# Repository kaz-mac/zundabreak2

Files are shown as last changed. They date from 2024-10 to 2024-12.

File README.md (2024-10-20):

# 30分以上PCの前にいるとずんだもんが休憩を促すデバイス for M5Stack ATOMS3

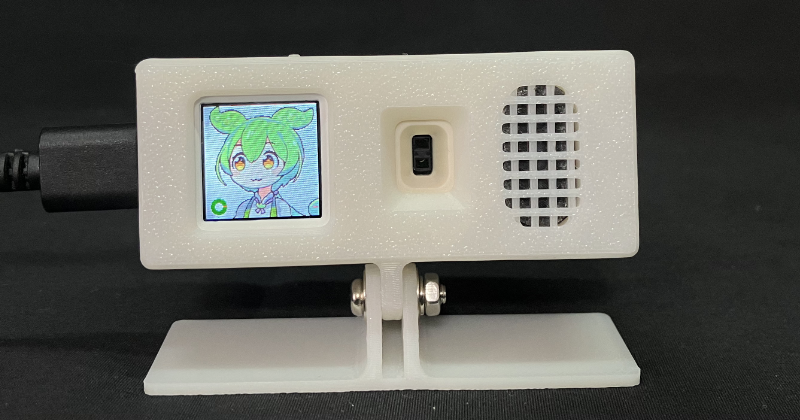
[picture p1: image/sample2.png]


## これは何？
30分以上PCの前にいたら休憩を促すメッセージを再生するデバイスです。PCの画面に長時間向かっていると目に負担がかかるので、目を休めつつ、気分転換を図るのが狙いです。腰痛防止にもいいのだ。

## 必要なもの
* M5Stack [ATOMS3](https://shop.m5stack.com/products/atoms3-dev-kit-w-0-85-inch-screen)
* M5Stack [Unit-ToF4M](https://shop.m5stack.com/products/time-of-flight-distance-unit-vl53l1x) (VL53L1X)
* M5Stack [Speaker 2 Hat](https://shop.m5stack.com/products/m5stickcplus-speaker-2-hat-max98357) (MAX98357)、（[ATOMIC Speaker Base](https://shop.m5stack.com/products/atomic-speaker-base-ns4168)も使用可）

## しくみ
ToFセンサーを使って対象物（人間）までの距離を測定します。指定した範囲内に人が存在する場合、PCの前にいると判断します。PCの前にいる時間が一定時間を超えると働きすぎと判断して、休憩を促すメッセージを再生します。

物体を検出するセンサーとしてはPIRセンサーが有名ですが、PIRセンサーでは距離が測れないため、PCの前にいるのか、離れた場所にいるのかを区別できません。また検知する角度も広いので他の人にも反応してしまいます。今回使用したUnit-ToF4Mは検知する範囲の角度が狭いので、人間くらいの大きさならピンポイントで測定できます。

## ディレクトリ構成
* [src/](src/) ... M5Stackのプログラム
* [psdlayers2rgb565/](psdlayers2rgb565/) ... PSD形式の画像からRGB565形式に一括変換するプログラム
* [STL/](STL/) ... ケースの3Dプリント用データ

<br>

# 作り方

## ライブラリのインストール
以下のライブラリがインストールされていない場合は、先にインストールします。
* M5Unified
* ESP8266Audio
* VL53L1X
* Ticker

## プログラムのコンパイル
zundabreak2 というフォルダを作成して、src/ フォルダ内のファイルをコピーします。コンパイルしてATOMS3に書き込みます。なお、オプション設定はUSB CDC On Boot: Enabled、USB Mode: Hardware CDC and JTAGにしています。

## ケースをプリントする場合
STLフォルダに3種類のケースが入っているので好きなのを使ってください。
* STL/Standard ... 改造・はんだ付け不要でジャンパーワイヤーで接続できます。
* STL/Mini ... コンパクトなタイプ。スピーカーをケースから取り出してはんだ付けします。
* STL/misc ... Miniのスタンド部分なしバージョン

脱落防止の突起があるのでケースを広げながら出し入れしてみてください。かなり硬めです。ATOMS3を取り出すときは、画面部分を強く押さないように注意！取り出すときはケースをニッパ等で破壊することを推薦します。

## ケースを使わない場合
[Speaker 2 Hat](https://shop.m5stack.com/products/m5stickcplus-speaker-2-hat-max98357) ではなく [ATOMIC Speaker Base](https://shop.m5stack.com/products/atomic-speaker-base-ns4168) を使えばジャンパーワイヤーなしで使えます。ピンアサインはATOMIC Speaker Baseに合わせていますので、そのままコンパイルしても使えます。

## 配線
はじめにATOMS3のGroveポートとToFセンサーを接続します。次にATOMS3のGPIOポートとスピーカーを接続します。ピンアサインは以下の通り。
| Speaker 2 HAT | ATOMS3 | 参考(M5StickC Plusのピンアサイン) |
| --- | --- | --- |
| GND | GND | GND |
|  |  | 5V |
| BCLK | G5 | G26 |
| SDATA | G38 | G36/G25 |
| LRCK | G39 | G0 |
|  |  | BAT |
| 3V3 | 3V3 | 3V3 |
|  |  | 5V |

Speaker 2 HATはM5StickC Plus用の製品なので、そのままでは使用できませんが、ATOMS3のGPIOに合わせて接続してあげれば使用できます。

## センサーが反応する距離を調整
自分の環境に合わせてセンサーが反応する距離を調整します。ボタン（画面の方）を押しながら電源を入れるとデバッグモードに入ります。デバッグモードでは距離(cm)と範囲のゲージが表示されるので、もし合わない場合は後述するカスタマイズのところを参考に値を修正してください。

## 電源オン
デフォルトでは指定した範囲内に居る場合は、アヒルちゃんが表示されます。ToFセンサーは指向性が高いので、正面に置いていると、体を動かしたときに範囲外になってしまうかもしれません。アヒルちゃんで確認しましょう。もし範囲外になって使いにくい場合は、横側に置くという手もあります。

## ボタン操作
短押し ... いきなり休憩モード<br>
長押し ... 次の状態へ遷移

<br>

# カスタマイズ

## 基本的なカスタマイズ方法
zundabreak2.ino の冒頭に設定項目があるので、好みで調整してください。
| 変数名 | 用途 | 単位 | デフォルト値 |
| --- | --- | --- | --- |
| WORK_LIMIT | 休憩を促すまでの時間 | s | 1800 | 
| BREAK_TIME_LONG | 休憩の長さ | s | 90 |
| DISPLAY_DISTANCE_MIN | PCの前にいると判断する位置 MIN | mm | 250 |
| DISPLAY_DISTANCE_MAX | PCの前にいると判断する位置 MAX | mm | 750 |
```cpp
const uint32_t WORK_LIMIT = 1800;       // 30分以上働いたら休憩を促す(s)
const uint32_t BREAK_TIME_LONG = 90;    // 休憩の長さ(s)
const int DISPLAY_DISTANCE_MIN = 250;   // PCの前にいると判断する位置 MIN (mm)
const int DISPLAY_DISTANCE_MAX = 750;   // PCの前にいると判断する位置 MAX (mm)
```

## 応用的ななカスタマイズ
```cpp
const int TIRED_LIMIT_1 = 85;   // 疲労レベル閾値1 (0-100)  85=約25分後
const int TIRED_LIMIT_2 = 95;   // 疲労レベル閾値2 (0-100)  95=約28分後
const bool SHOW_DISTANCE_GAUGE = true;  // 距離確認用のゲージを常に表示する
const bool SHOW_DISTANCE_AHIRU = true;  // 距離確認用のアヒルちゃんを表示する
const uint32_t BLINK_TIME_BASE = 2000;  // まばたき時間　基本間隔
const uint32_t BLINK_TIME_RAND = 2000;  // まばたき時間　ランダム追加 max
const uint32_t BLINK_TIME_CLOS = 150;   // まばたき時間　閉じてる時間
const uint32_t KYORO_TIME_BASE = 1500;  // キョロキョロ時間　基本間隔
const uint32_t KYORO_TIME_RMAX = 2000;  // キョロキョロ時間　ランダム追加 max
```

## 音声を変えたい
自分でWAVファイルを作成することもできます。data_sound_zundamon.h に変数名のところを変えてデータをコピペしてください。変換は psdlayers2rgb565/ に入ってる file2h.py を使うと便利です。Pythonが必要です。ビットレートを24KHz以外にする場合は適宜修正してください。
```
python file2h.py input.wav output.h
```

## 音量を変えたい
WAVファイル作成の段階で変更する必要があるそうです。（とChatGPTが言ってた）

## 表情を変えたい
ずんだもんのアバターは体、右腕、左腕、眉毛、目、口、アヒルちゃん、それぞれのパーツを組み合わせて生成されています。この数字の部分を変えれば別のパーツになります。番号は data_image_zundamon128.h の「画像パーツの部位別テーブル」のところを参考にしてみてください。
```cpp
  avatar.changeParts("body", 0);    // 体
  avatar.changeParts("rhand", 0);   // 右腕
  avatar.changeParts("lhand", 0);   // 左腕
  avatar.changeParts("eyebrow", 0); // 眉毛
  avatar.changeParts("eye", 1);     // 目
  avatar.changeParts("mouth", 0);   // 口
  avatar.changeParts("ahiru", 0);   // アヒル
```
なお、まばたきやキョロキョロ（視線を左右に変えること）は別途設定しています。キョロキョロは変数 kyoroEyePattern で設定しています。
```cpp
const uint8_t kyoroEyePattern[3][kyoroEyeNum] = {  // キョロキョロする目のインデックス番号：目　普通
  { 3,1,2,1 }, { 6,4,5,4 }, { 9,7,8,7 }   // 元気なとき、少し疲れたとき、かなり疲れたとき
};
```
まばたきは以下のように設定しています。
```cpp
avatar.setBlink("eye", 1, 0);
```

## 別の画像を使いたい
ずんだもんじゃなくて四国めたんがいいですか？ psdlayers2rgb565/ はPSD形式の画像ファイルからC++のソースコード形式に変換するプログラムが入ってますので、これを使えばできると思います。Pythonが必要です。詳しくは[こちら](https://github.com/kaz-mac/zundachan/tree/main/tools)にあるズンダチャン用に作ったドキュメントを参考にしてください。

主な同梱ファイル
* image_zundamon128.ini ... 坂本アヒルさんのずんだもん立ち絵素材から.hファイルに変換するための設定ファイル
* convert_zundamon128.bat ... 一連の変換処理を一発で行うバッチファイル
設定ファイルの記述方法は image_zundamon128.ini にコメントがあります。

## License
個別に表記しているものを除き、プログラムは[MIT license](https://opensource.org/licenses/MIT)です。<br>
音声データ、画像データ、およびキャラクターに関してはライセンス・利用規約が異なります。

[東北ずん子ずんだもんプロジェクト　キャラクター　利用の手引き](https://zunko.jp/guideline.html)<br>
[ずんだもん立ち絵素材](https://www.pixiv.net/artworks/92641351)<br>
[VOICEVOX ソフトウェア利用規約](https://voicevox.hiroshiba.jp/term/)<br>

## Credit
* 画像データ 坂本アヒルさん
* キャラクター 東北ずん子ずんだもんプロジェクト
* 音声データ VOICEVOX: ずんだもん

## 作例
STL/Standatd/ のケースを使用した場合（ジャンパーワイヤーで配線）
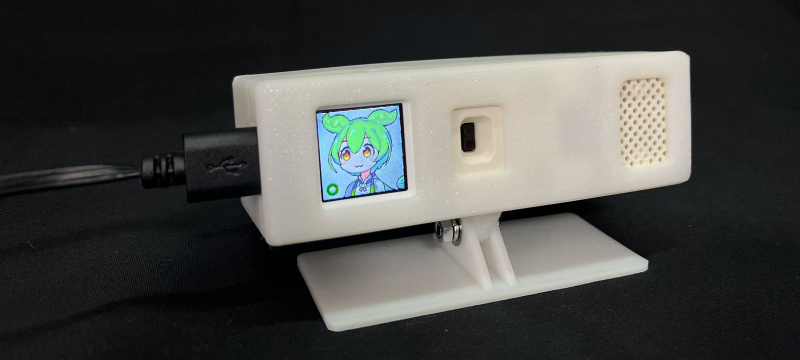
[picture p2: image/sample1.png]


STL/Mini/ のケースを使用した場合（内部）
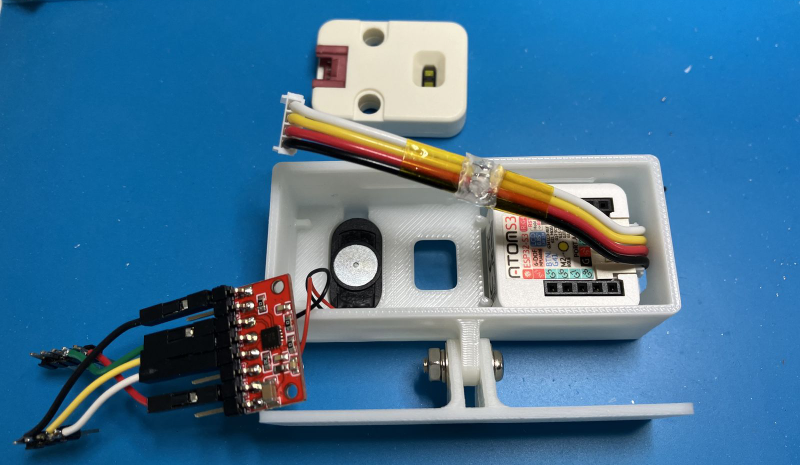
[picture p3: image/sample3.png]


ATOMIC Speaker Baseを使用した例
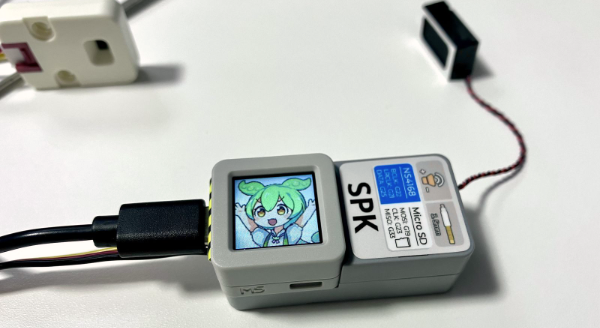
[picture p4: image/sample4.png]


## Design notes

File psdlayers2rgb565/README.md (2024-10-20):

# 概要
PSD形式の画像ファイルからレイヤーを抽出して合成し、Arduino用で使用できるC++のソースコード形式(RGB565)に変換するツールです。サウンドファイル等のバイナリデータをソースコード形式に変換するツールも含まれています。

# ドキュメント
このプログラムはズンダチャンに収録したツールの一部です。詳しくはこちらのドキュメントを参考にしてください。<br>
[https://github.com/kaz-mac/zundachan/tree/main/tools](https://github.com/kaz-mac/zundachan/tree/main/tools)

# 本プロジェクト用に作成したファイル
* image_zundamon128.ini - ずんだもん 分解設定ファイル 128x128用
* convert_zundamon128.bat - 一連の変換処理を一括で行うバッチファイル

# ライブラリのインストール
```
pip install pillow
pip install psd-tools
```
Python 3.11で動作確認。3.13ではpsd-toolsがインストールできなかった。

# 使用例
PSD画像を分解
```
python psdlayers2png.py "ずんだもん立ち絵素材2.3.psd" image_zundamon128_png
```
分解した画像データを.hファイルに変換
```
python pngmerger_rgb565.py image_zundamon128.ini image_zundamon128_png zundamon128.h
```
WAVファイルを.hファイルに変換
```
python file2h.py input.wav output.h
```

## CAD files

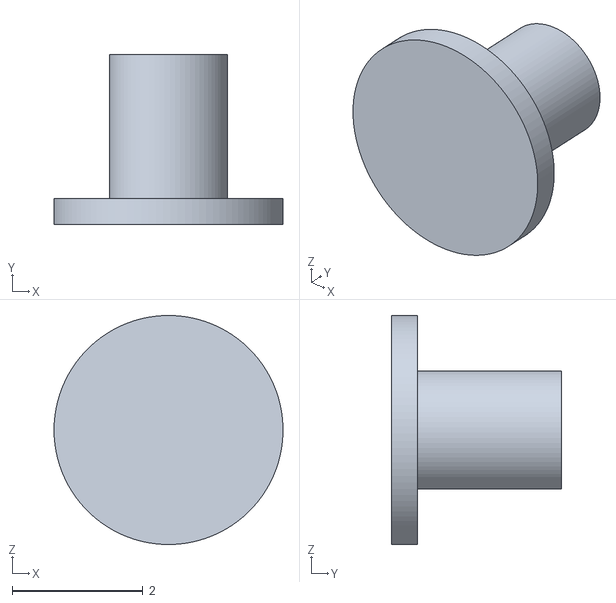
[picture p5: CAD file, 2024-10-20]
STL/Mini/Zuntimer_Mbutton.stl
3.50 x 2.60 x 3.50

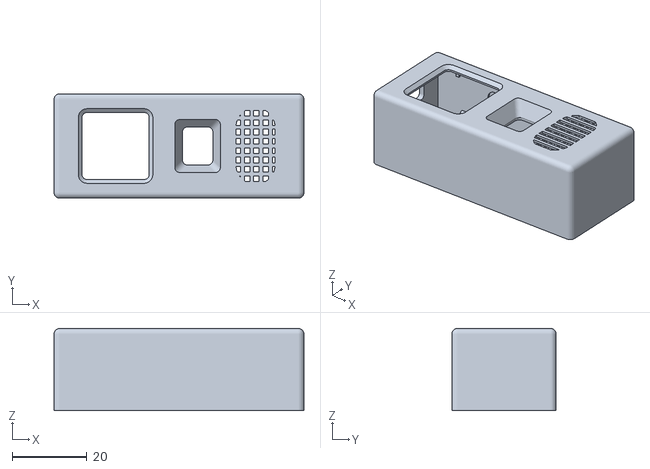
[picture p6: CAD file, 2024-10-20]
STL/misc/Zuntimer_Mbody_without_stand.stl
67.0 x 28.0 x 22.0

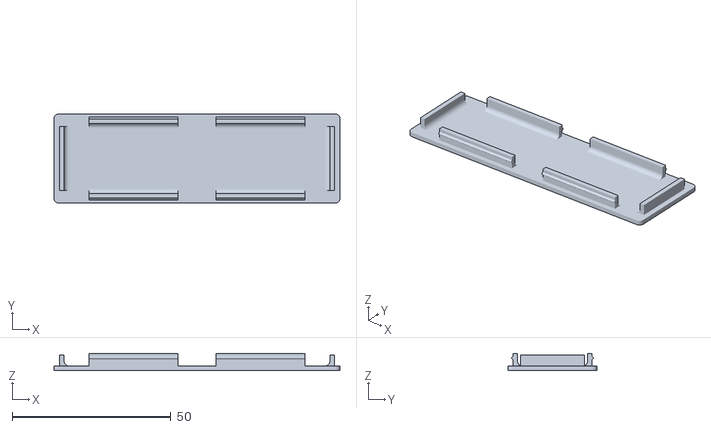
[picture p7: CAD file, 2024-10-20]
STL/Standard/Zuntimer_cover.stl
90.0 x 28.0 x 5.50

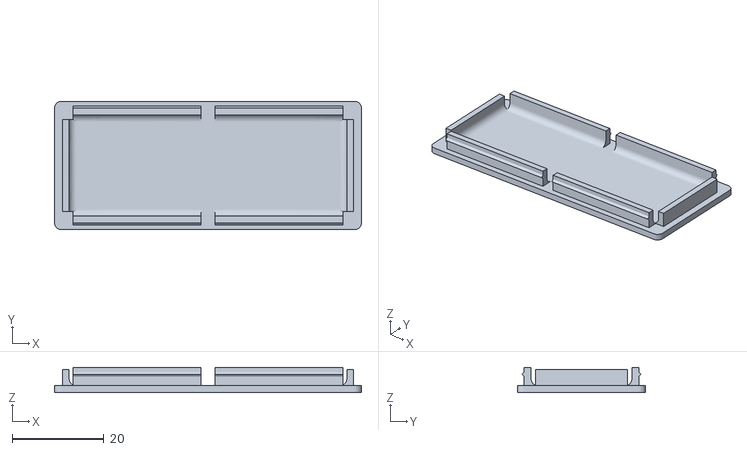
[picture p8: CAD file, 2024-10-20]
STL/Mini/Zuntimer_Mcover.stl
67.0 x 28.0 x 5.50

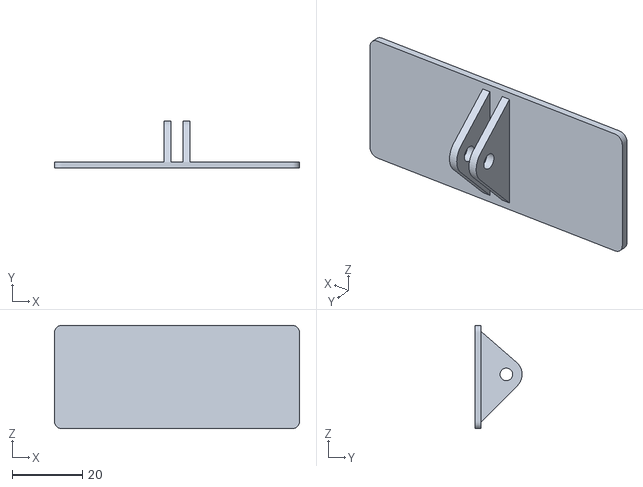
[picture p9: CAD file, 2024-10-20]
STL/Standard/Zuntimer_stand.stl
70.0 x 13.5 x 29.5

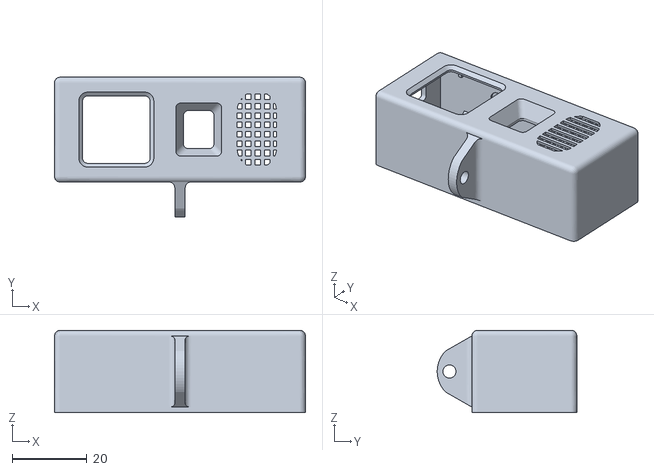
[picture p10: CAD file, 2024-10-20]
STL/Mini/Zuntimer_Mbody.stl
67.0 x 37.3 x 22.0

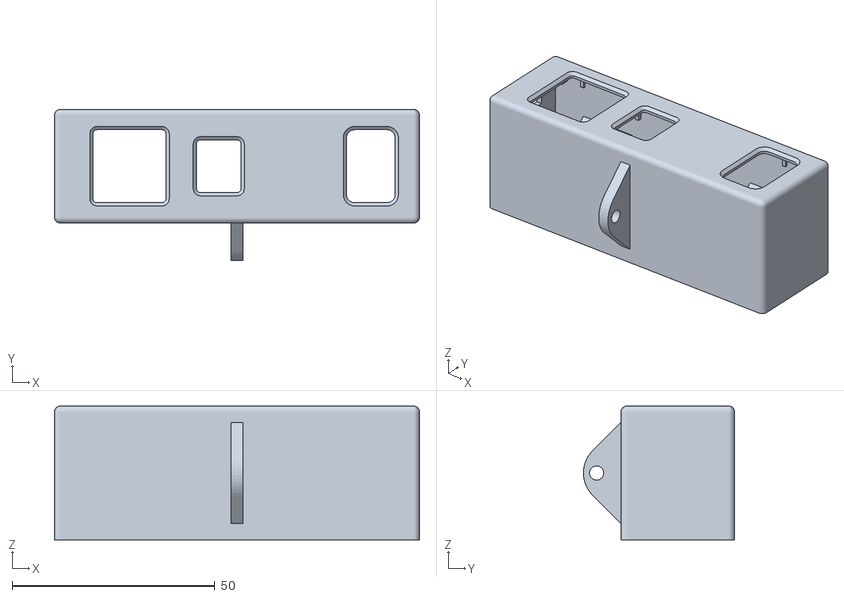
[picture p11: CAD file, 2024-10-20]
STL/Standard/Zuntimer_body.stl
90.0 x 37.3 x 33.0

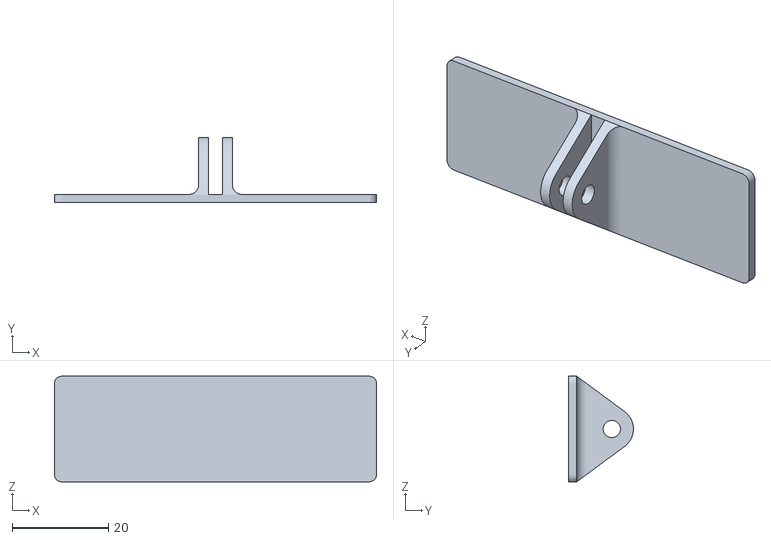
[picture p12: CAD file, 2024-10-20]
STL/Mini/Zuntimer_Mstand.stl
67.0 x 13.5 x 22.0

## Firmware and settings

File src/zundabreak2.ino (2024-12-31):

/*
  zundabreak2.ino
  30分以上PCに向かっているとずんだもんが休憩を促すデバイス for M5Stack ATOMS3
  ToFセンサー Unit-ToF4M使用

  Copyright (c) 2024 Kaz  (https://akibabara.com/blog/)
  Released under the MIT license.
  see https://opensource.org/licenses/MIT

  CREDIT
    画像データ 坂本アヒルさん
    キャラクター　東北ずん子ずんだもんプロジェクト
    音声データ VOICEVOX: ずんだもん

  ※本プログラムはMITライセンスですが（個別に記載があるものを除く）、
  音声データ、画像データ、およびキャラクターに関しては、それぞれの
  ライセンス・利用規約が適用されます。
*/
/*
TODO:
  Ticker once_msでも良くない？
  deep sleepに対応したい　参考 https://qiita.com/yomori/items/ef20d888a79aaedb58fe
*/
#include <M5Unified.h>

// 基本動作設定
const uint32_t WORK_LIMIT = 1800;       // 30分以上働いたら休憩を促す(s)
const uint32_t BREAK_TIME_LONG = 90;    // 休憩の長さ(s)
const int DISPLAY_DISTANCE_MIN = 250;   // PCの前にいると判断する位置 MIN (mm)
const int DISPLAY_DISTANCE_MAX = 750;   // PCの前にいると判断する位置 MAX (mm)

// その他動作設定
const int TIRED_LIMIT_1 = 85;   // 疲労レベル閾値1 (0-100)  85=約25分後
const int TIRED_LIMIT_2 = 95;   // 疲労レベル閾値2 (0-100)  95=約28分後
const bool SHOW_DISTANCE_GAUGE = true;  // 距離確認用のゲージを常に表示する
const bool SHOW_DISTANCE_AHIRU = true;  // 距離確認用のアヒルちゃんを表示する
const uint32_t BLINK_TIME_BASE = 2000;  // まばたき時間　基本間隔
const uint32_t BLINK_TIME_RAND = 2000;  // まばたき時間　ランダム追加 max
const uint32_t BLINK_TIME_CLOS = 150;   // まばたき時間　閉じてる時間
const uint32_t KYORO_TIME_BASE = 1500;  // キョロキョロ時間　基本間隔
const uint32_t KYORO_TIME_RMAX = 2000;  // キョロキョロ時間　ランダム追加 max

// GPIO設定 ATOMS3
#define GPIO_SDA  2   // Grove SDA
#define GPIO_SCL  1   // Grove SCL
#define GPIO_I2S_BCLK  5    // I2S BCLK (Atomic SPK Base compatible)
#define GPIO_I2S_LRCK  39   // I2S LRCK (Atomic SPK Base compatible)
#define GPIO_I2S_DATA  38   // I2S DATA (Atomic SPK Base compatible)

// アバター関連
#include "Zundavatar.h"   // アバタークラス
using namespace zundavatar;
bool lcdBusy = false;   // ディスプレイの排他制御用　クラス間で共有される
Zundavatar avatar(&lcdBusy);

// アバター画像データ
#include "data_image_zundamon128.h"   // 画像データ　ずんだもん

// オーディオ出力関連
#include <AudioFileSourcePROGMEM.h>
#include <AudioGeneratorWAV.h>
#include <AudioOutputI2S.h>
AudioGeneratorWAV *wav;
AudioFileSourcePROGMEM *file;
AudioOutputI2S *out;

// 音声データ
#include "data_sound_zundamon.h"   // 音声データ　ずんだもん
const int SAMPLE_RATE = 24000;
const unsigned char* soundData[] = { sound000, sound001, sound002 };
const size_t sizeData[] = { sizeof(sound000), sizeof(sound001), sizeof(sound002) };

// ToF距離センサー関係 Unit-ToF4M使用
#include <Wire.h>
#include <VL53L1X.h>
VL53L1X tof;

// 割り込み処理
#include <Ticker.h>
Ticker tickerk;
volatile bool refresh;

// グローバル変数
M5Canvas tgauge, tinfo;
M5Canvas red, blue, green, purple;
bool blink = false;
uint16_t blinkOpen = 1;
bool kyoro = false;
bool tofok = false;

// デバッグに便利なマクロ定義 -- M5.Log置き換えver --------
// 参考ページ https://github.com/lovyan03/M5Unified_HandsOn/blob/main/sample_code/Log1.cpp
#define sp(x) M5.Log.println(String(x).c_str())
#define spn(x) M5.Log.print(String(x).c_str())
#define spp(k,v) M5.Log.println(String(String(k)+"="+String(v)).c_str())
#define spf(fmt, ...) M5.Log.printf(fmt, __VA_ARGS__)
#define array_length(x) (sizeof(x) / sizeof(x[0]))


// ====================================================================================

// 体力ゲージのイメージを作成する
void drawHpGage(M5Canvas* canvas, int tired) {
  int c;
  int w = canvas->width();
  int h = canvas->height();
  canvas->fillSprite(0x0020);   // 透明色で塗りつぶし
  c = 360 * ((float)(100 - tired) / 100.0);
  canvas->fillArc(w/2,h/2, 5,9, 0,c, TFT_DARKGREEN);
  if (c > 0) canvas->fillArc(w/2,h/2, 5,9, c,360, TFT_RED);
}

// 距離ゲージのイメージを作成する
void drawDistanceGage(M5Canvas* canvas, int now, int limitLow, int limitHigh, int maxDepth=4000) {
  int y;
  int w = canvas->width();
  int h = canvas->height();
  if (now < 0) now = 0;
  if (now > maxDepth) now = maxDepth;
  //canvas->fillSprite(TFT_WHITE);   // 背景色で塗りつぶし
  canvas->fillSprite(0x0020);   // 透明色で塗りつぶし
  y = (h-1) - (h-1) * ((float)limitLow / maxDepth);
  canvas->drawLine(w/2,y, w-1,y, TFT_DARKGREEN);
  y = (h-1) - (h-1) * ((float)limitHigh / maxDepth);
  canvas->drawLine(w/2,y, w-1,y, TFT_DARKGREEN);
  y = (h-1) - (h-1) * ((float)now / maxDepth);
  canvas->drawLine(0,y, w-1,y, TFT_RED);
}

// デバッグモード：矢印付きゲージのイメージを作成する
void drawArrowGage(M5Canvas* canvas, int now, int limitLow, int limitHigh, int maxDepth=4000) {
  int x, y, x1, x2;
  int w = canvas->width();
  int h = canvas->height();
  if (now < 0) now = 0;
  if (now > maxDepth) now = maxDepth;
  canvas->fillSprite(0x0020);   // 透明色で塗りつぶし
  canvas->drawRect(1,9, w-2, 12, TFT_BLACK);
  canvas->fillRect(2,10, w-4, 10, TFT_SKYBLUE);
  x1 = (w-4) * ((float)limitLow / maxDepth);
  x2 = (w-4) * ((float)limitHigh / maxDepth);
  canvas->fillRect(x1+2,10, (x2-x1), 10, TFT_GREEN);
  x = (w-4) * ((float)now / maxDepth);
  y = 8;
  canvas->fillRect(x-1,1, 3,h-1, TFT_RED);
  canvas->fillTriangle(x,y, x-6,y-7, x+6, y-7, TFT_RED);
}

// デバッグモード：距離メーターのイメー時を作成する
void drawDebugDistance(M5Canvas* canvas, int distance, bool fuchi=false) {
  int w = canvas->width();
  int x, y;
  canvas->fillSprite(0x0020);   // 透明色で塗りつぶし
  canvas->setFont(&fonts::Font4); // 14x26
  canvas->setTextDatum(textdatum_t::top_right);
  String text = String(distance / 10) + "cm";
  x = w - 2;
  y = 2;
  if (fuchi) {
    canvas->setTextColor(TFT_WHITE);
    for (int i=-1; i<=1; i++) {
      for (int j=-1; j<=1; j++) {
        canvas->drawString(text, x+i, y+j);
      }
    }
  }
  canvas->setTextColor(TFT_BLACK);
  canvas->drawString(text, x, y);
}

// デバッグモード：ToFセンサー距離調整をするためのモード
void debugmode() {
  // ゲージと距離表示のcanvasを作成
  tgauge.setColorDepth(16);
  tgauge.createSprite(128, 20);
  avatar.setInsertedLayer(0, OVR_FRONT_AVATER, &tgauge, 0,108);   // ゲージのcanvasをアバターに挿入設定
  tinfo.setColorDepth(16);
  tinfo.createSprite(80, 30);
  avatar.setInsertedLayer(1, OVR_FRONT_AVATER, &tinfo, 128-80,0);   // 距離メーターのcanvasをアバターに挿入設定
  while (1) {
    M5.update();
    // 距離を測定
    int distance = tof.readRangeContinuousMillimeters();
    spp("distance",distance);
    // 距離に応じてずんだもんの表情を変える
    defaultAvatarParts();
    if (distance < DISPLAY_DISTANCE_MIN) {  // 近すぎる場合
      avatar.changeParts("eye", 13);     // 目　ジト目
      avatar.changeParts("mouth", 11);   // 口　△
      avatar.changeParts("rhand", 3);   // 右腕　口元
    } else if (distance > DISPLAY_DISTANCE_MAX) { // 遠すぎる場合
      avatar.changeParts("body", 1);    // 体　萎え
      avatar.changeParts("eye", 14);     // 目　なごみ
    } else {  // 範囲内の場合
      avatar.changeParts("eye", 1);     // 目　普通　開く（中）
      avatar.changeParts("mouth", 1);   // 口　普通　（ほあー）
      avatar.changeParts("rhand", 2);   // 右腕　上げ
      avatar.changeParts("lhand", 2);   // 左腕　上げ
    }
    drawArrowGage(&tgauge, distance, DISPLAY_DISTANCE_MIN, DISPLAY_DISTANCE_MAX, 1500); // ゲージを作成
    drawDebugDistance(&tinfo, distance, true);  // 距離メーターを作成
    avatar.drawAvatar(); // アバター全体表示
    delay(100);
  }
}

// 配列の中に指定した値があるか？
// bool inArray(uint16_t value, const uint16_t* array, size_t size) {
//   for (size_t i = 0; i < size; i++) {
//     if (array[i] == value) return true;
//   }
//   return false;
// }

// アバターのパーツをデフォルトに設定する
void defaultAvatarParts() {
  avatar.changeParts("body", 0);    // 体
  avatar.changeParts("rhand", 0);   // 右腕
  avatar.changeParts("lhand", 0);   // 左腕
  avatar.changeParts("eyebrow", 0); // 眉毛
  avatar.changeParts("eye", 1);     // 目
  avatar.changeParts("mouth", 0);   // 口
  avatar.changeParts("ahiru", 0);   // アヒル
}

// 指定時間待機する。待機中もM5.update()を行っており、ボタンが押されたら即座に抜ける
bool waitMillis(uint32_t ms) {
  bool res = false;
  uint32_t tmwait = millis() + ms;
  while (millis() < tmwait) {
    M5.update();
    if (M5.BtnA.isPressed()) {
      res = true;
      break;
    }
    delay(10);
  }
  return res;
}

// 喋ると同時にリップシンクを行う
void playVoice(int no, bool withlip) {  // Default: withlip=false
  const int lipsyncDuration = 200;  // リップシンクの間隔(ms)
  unsigned long stams = millis();
  unsigned long lastms = 0;

  // 再生開始
  file = new AudioFileSourcePROGMEM(soundData[no], sizeData[no]);
  wav = new AudioGeneratorWAV();
  wav->begin(file, out);
  while (wav->isRunning()) {
    wav->loop();

    // リップシンク
    if (withlip && (millis() - lastms) >= lipsyncDuration) {
      // 平均音量を計算
      int idx = ((millis() - stams) * SAMPLE_RATE) / 1000 * 2;
      int numSamples = (lipsyncDuration * SAMPLE_RATE) / 1000;
      int totalSamples = 0;
      long totalVolume = 0;
      for (int i = 0; i < numSamples; i++) {
        if ((idx + i*2 + 1) >= sizeData[no]) break;
        int16_t val = soundData[no][idx + i*2] | (soundData[no][idx + i*2 + 1] << 8);
        totalVolume += abs(val);
        totalSamples++;
      }
      int averageVolume = (totalSamples > 0) ? totalVolume / totalSamples : 0;
      // 音の大きさに合わせてアバターの口を変更（閾値は要調整）
      if (averageVolume > 1000)     avatar.setLipsyncVowel(5, 80);  // "o" 80ms  口　お　（お）
      else if (averageVolume > 100) avatar.setLipsyncVowel(2, 80);  // "a" 80ms　口　あ　（ほあー）
      else                          avatar.setLipsyncVowel(0, 1);   // "n" 1ms
      lastms = millis();
    }
    delay(5);
  }

  // 再生終了
  wav->stop();
  if (withlip) avatar.setLipsyncVowel(0, 1);
}

// Tiker処理：自動的にキョロキョロする（描画はせず、refreshフラグを立てるのみ）
uint16_t kyoroEyeSelect = 0;  // キョロキョロパターンの選択
static constexpr uint16_t kyoroEyeNum = 4;      // キョロキョロする目の数
const uint8_t kyoroEyePattern[3][kyoroEyeNum] = {  // キョロキョロする目のインデックス番号：目　普通
  { 3,1,2,1 }, { 6,4,5,4 }, { 9,7,8,7 }   // 元気なとき、少し疲れたとき、かなり疲れたとき
};
void startKyorokyoro() {
  if (tickerk.active()) return;
  uint32_t kyoroms = KYORO_TIME_BASE + random(0, KYORO_TIME_RMAX);
  tickerk.attach_ms(kyoroms, tickerKyorokyoro);
}
void tickerKyorokyoro() {
  static uint16_t pat = 0;
  int krrand = random(0,3);// pat++ % kyoroEyeNum
  if (blink) {
    avatar.setBlink("eye", kyoroEyePattern[kyoroEyeSelect][krrand], 0);   // まばたきの目の設定を変更　注意：変更すると即座に反映されるのでrefreshは不要
  } else {
    avatar.changeParts("eye", kyoroEyePattern[kyoroEyeSelect][krrand]);   // 目を変更
    refresh = true;
  }
  // 次回実行間隔をランダムに変える
  if (tickerk.active()) {
    uint32_t kyoroms = KYORO_TIME_BASE + random(0, KYORO_TIME_RMAX);
    tickerk.detach();
    tickerk.attach_ms(kyoroms, tickerKyorokyoro);
  }
}
void stopKyorokyoro() {
  if (!tickerk.active()) return;
  tickerk.detach();
}

// 空きメモリ確認
void debug_free_memory(String str) {
  sp("## "+str);
  spf("heap_caps_get_free_size(MALLOC_CAP_DMA):%d\n", heap_caps_get_free_size(MALLOC_CAP_DMA) );
  spf("heap_caps_get_largest_free_block(MALLOC_CAP_DMA):%d\n", heap_caps_get_largest_free_block(MALLOC_CAP_DMA) );
  spf("heap_caps_get_free_size(MALLOC_CAP_SPIRAM):%d\n", heap_caps_get_free_size(MALLOC_CAP_SPIRAM) );
  spf("heap_caps_get_largest_free_block(MALLOC_CAP_SPIRAM):%d\n\n", heap_caps_get_largest_free_block(MALLOC_CAP_SPIRAM) );
}

// ====================================================================================

// 初期化
void setup() {
  // 初期化
  auto cfg = M5.config();
  // cfg.external_spk = true;  // 別に設定しなくても変わらなかったから意味ないかも??
  // cfg.serial_baudrate = 115200;
  M5.begin(cfg); 
  Wire.begin(GPIO_SDA, GPIO_SCL);
  delay(1000);
  sp("Start!");
  debug_free_memory("Start");

  // ログレベルの設定
  // M5.Log.setLogLevel(m5::log_target_serial, ESP_LOG_INFO); // 表示するログレベル ERROR WARN INFO DEBUG VERBOSE
  // M5.Log.setEnableColor(m5::log_target_serial, false);  // ログカラー

  // スピーカーI2S出力設定
  out = new AudioOutputI2S();
  out->SetPinout(GPIO_I2S_BCLK, GPIO_I2S_LRCK, GPIO_I2S_DATA);       // BCLK, DATA, LRCLK
  out->SetRate(SAMPLE_RATE);

  // ディスプレイの設定
  M5.Lcd.init();
  M5.Lcd.setRotation(3);
  M5.Lcd.setColorDepth(16);
  M5.Lcd.fillScreen(TFT_WHITE);

  // ToFセンサーの設定
  tof.setBus(&Wire);
  tof.setTimeout(500);
  tofok = tof.init();
  if (tofok) {
    tof.setDistanceMode(VL53L1X::Long);
    tof.setMeasurementTimingBudget(50000);
    tof.startContinuous(50);
  } else {
    sp("Failed to detect and initialize ToF sensor!");
    M5.Lcd.fillScreen(TFT_RED);
    delay(3000);
  }

  // アバターの設定
  avatar.usePSRAM(false);   // PSRAMを使わない（128x128ならメインメモリに収まるし速度も速いから）
  String tableNames[]   = { "body", "rhand", "lhand", "eyebrow", "eye", "mouth", "ahiru" };  // 部位名（imgTablesと順番を揃える）
  uint16_t* imgTables[] = { imgTableBody, imgTableRhand, imgTableLhand, imgTableEyebrow, imgTableEye, imgTableMouth, imgTableAhiru };  // 部位ごとにリスト化した表（テーブル）
  avatar.setImageData(imgInfo, tableNames, imgTables, 7); // 画像データを登録する
  avatar.useAntiAliases = true; // アンチエイリアス処理をする
  avatar.mirrorImage = false;   // 左右反転しない（反転はバグあり）
  avatar.setDrawDisplay(&M5.Lcd, 0,0, TFT_WHITE); // アバターの表示先を設定する（出力先, x, y, 背景色）
  avatar.debugtable();
  debug_free_memory("after avater setting");

  // アバターの表示
  defaultAvatarParts(); // アバターのパーツをデフォルトに設定する
  avatar.drawAvatar();  // アバター全体表示

  // ボタン押しながら電源を入れたらデバッグモードに移行
  if (M5.BtnA.isPressed()) {
    debugmode();  // ToFセンサー距離調整デバッグモード
  }

  // アバターのまばたきの設定と開始
  avatar.setBlink("eye", 1, 0);   // まばたき用のインデックス番号を設定する
  avatar.blink_wait1 = BLINK_TIME_BASE;  // 基本間隔
  avatar.blink_wait2 = BLINK_TIME_RAND;  // ランダム追加 max
  avatar.blink_wait3 = BLINK_TIME_CLOS;  // 閉じてる時間
  avatar.startAutoBlink();  // 自動まばたきスタート（タスク実行）
  blink = true;

  // アバターのリップシンクの設定と開始
  avatar.setLipsync("mouth", 0, 2, 3, 4, 5, 6);   // リップシンク用のインデックス番号を設定する
  avatar.startAutoLipsync();  // リップシンクをスタート（タスク実行）

  // ボイス再生
  playVoice(0, true);  // 「がんばるのだ」
  avatar.changeParts("mouth", 0);   // ボイス再生後は念のため口を戻す：口　閉じ　（むふ）
  avatar.drawAvatar();  // アバター全体表示

  // アバターに挿入するcanvasの設定
  tgauge.setColorDepth(16);
  tgauge.createSprite(20, 20);
  tgauge.fillSprite(0x0020);   // 透明色で塗りつぶし
  avatar.setInsertedLayer(0, OVR_FRONT_AVATER, &tgauge, 4,104);   // ゲージのcanvasをアバターに挿入設定
  if (SHOW_DISTANCE_GAUGE) {
    tinfo.setColorDepth(16);
    tinfo.createSprite(6, 128);
    tinfo.fillSprite(0x0020);   // 透明色で塗りつぶし
    avatar.setInsertedLayer(1, OVR_FRONT_AVATER, &tinfo, 121,0);   // ゲージのcanvasをアバターに挿入設定
  }

  // 準備完了
  sp("initialize done!");
  delay(1000);
}


// ====================================================================================

// メイン
void loop() {
  static uint32_t workingtime = 0;   // 働いた時間(s)
  static int stat = 0, laststat = 0;  // 現在の状態
  static int tired = 0;  // 疲労度 0～100%
  int distance = 0;   // 距離(mm)
  M5.update();

  // デバッグ用　ボタンを長押ししたら状態変更
  if (M5.BtnA.pressedFor(500)) {
    while (!M5.BtnA.wasReleased()) {  // ボタンを離すまで待機　★★★
      M5.update();
      delay(5);
    }
    M5.update();
    if (stat == 1) workingtime = WORK_LIMIT * ((float)TIRED_LIMIT_1 / 100);
    else if (stat == 2) workingtime = WORK_LIMIT * ((float)TIRED_LIMIT_2 / 100);
    else if (stat == 3) workingtime = WORK_LIMIT;
  }

  // ボタンを短押ししたら強制休憩モード
  if (M5.BtnA.wasReleased()) {
    sp("Lets break!");
    workingtime = WORK_LIMIT;
  }

  // 一定時間ごとに距離を計測する
  static uint32_t tm = 0;
  if (tm < millis() || laststat == 0) {
    bool hit = false;
    distance = (tofok) ? tof.readRangeContinuousMillimeters() : 0;
    if (distance >= DISPLAY_DISTANCE_MIN && distance <= DISPLAY_DISTANCE_MAX) {
      workingtime += 1;
      hit = true;
    }
    tm = millis() + 1000;  // 次回は1秒後に測定
    // 疲労レベルを計算する
    tired = ((float)workingtime / WORK_LIMIT) * 100;
    if (tired > 100) tired = 100;
    if (tired < TIRED_LIMIT_1) stat = 1;   // 元気
    else if (tired < TIRED_LIMIT_2) stat = 2;  // 少し疲れた
    else if (tired < 100) stat = 3; // かなり疲れた
    else stat = 4;  // もうムリ
    spf("distance=%d workingtime=%d tired=%d stat=%d\n", distance, workingtime, tired, stat);
    // 疲労ゲージと距離ゲージを作成する
    drawHpGage(&tgauge, tired);
    if (SHOW_DISTANCE_GAUGE) {
      drawDistanceGage(&tinfo, distance, DISPLAY_DISTANCE_MIN, DISPLAY_DISTANCE_MAX, 1500);
    }
    // アヒルちゃんのオンオフ
    if (SHOW_DISTANCE_AHIRU) {
      avatar.changeParts("ahiru", hit ? 1 : 0);   // アヒル
    }
    refresh = true;
  }

  // 状態stat変更時に1回のみ行う処理
  if (stat != laststat) {
    spp("new stat",stat);
    switch (stat) {
      case 1: // 元気
        defaultAvatarParts(); // アバターのパーツをデフォルトに戻す
        avatar.changeParts("eye", 1);     // 目　普通　開く（中）
        blinkOpen = 1;  // まばたき：目　普通　開く（中）
        blink = true;
        kyoroEyeSelect = 0;   // キョロキョロする目　普通
        kyoro = true;
        break;
      case 2: // 少し疲れた
        defaultAvatarParts(); // アバターのパーツをデフォルトに戻す
        avatar.changeParts("rhand", 1);   // 右腕　腰
        avatar.changeParts("lhand", 5);   // 左腕　考える
        avatar.changeParts("eyebrow", 2); // 眉　／ ＼　（下がり眉）
        avatar.changeParts("eye", 4);     // 目　普通2　開く（中）
        blinkOpen = 4;  // まばたき：目　普通2　開く（中）
        blink = true;
        kyoroEyeSelect = 1;   // キョロキョロする目　普通2
        kyoro = true;
        break;
      case 3: // かなり疲れた
        defaultAvatarParts(); // アバターのパーツをデフォルトに戻す
        avatar.changeParts("body", 1);    // 体　萎え
        avatar.changeParts("rhand", 3);   // 右腕　口元
        avatar.changeParts("lhand", 3);   // 左腕　口元
        avatar.changeParts("eyebrow", 4); // 眉　困り眉2
        avatar.changeParts("eye", 14);    // 目　なごみ
        avatar.changeParts("mouth", 0);   // 口　閉じ　（むふ）
        blinkOpen = 14;  // まばたき（しない）：目　なごみ
        blink = false;
        kyoro = false;
        break;
      case 4: // もうムリ
        blinkOpen = 1;  // まばたき（しない）：目　普通　開く（中）
        blink = false;
        kyoro = false;
        break;
    }
    refresh = true;
  }

  // まばたき（blink変更時に1回のみ行う処理）
  static bool lastblink = false;
  if (blink != lastblink) {
    if (blink) {
      avatar.setBlink("eye", blinkOpen, 0);   // まばたき用のインデックス番号を設定する
      avatar.startAutoBlink();  // 自動まばたきスタート（タスク実行）
    } else {
      avatar.stopAutoBlink();  // 自動まばたき停止
      avatar.changeParts("eye", blinkOpen);     // 目を戻す
      refresh = true;
    }
    lastblink = blink;
  }

  // キョロキョロ（kyoro変更時に1回のみ行う処理）
  static bool lastkyoro = false;
  if (kyoro != lastkyoro) {
    if (kyoro) {
      startKyorokyoro();  // キョロキョロ開始
    } else {
      stopKyorokyoro();  // キョロキョロ終了
      avatar.changeParts("eye", blinkOpen);     // 目を戻す
      refresh = true;
    }
    lastkyoro = kyoro;
  }

  // 一旦ここでアバターを表示する
  if (refresh) {
    avatar.drawAvatar(); // アバター全体表示
    refresh = false;
  }
  laststat = stat;
  delay(5);

  // 状態別の動作 1～3  状態：1=元気 2=少し疲れた、3=かなり疲れた
  if (stat >= 1 && stat <= 3) return;    // まだ頑張れるときはここで抜ける

  // 状態別の動作 4
  bool interrupt;
  if (stat == 4) {    // 状態：4=もうムリ
    // 体力ゲージと距離ゲージを一時的に非表示にする
    avatar.changeInsertedLayerPosition(0, OVR_NONE);   // 体力ゲージ
    if (SHOW_DISTANCE_GAUGE) avatar.changeInsertedLayerPosition(1, OVR_NONE);   // 距離ゲージ

    // 表情変更
    avatar.changeParts("body", 0);    // 体
    avatar.changeParts("rhand", 2);   // 右腕　上げ
    avatar.changeParts("lhand", 2);   // 左腕　上げ
    avatar.changeParts("eyebrow", 1); // 眉　＼ ／　（怒り眉）
    avatar.changeParts("eye", 1);     // 目　普通　開く（中）
    avatar.changeParts("mouth", 0);   // 口　閉じ　（むふ）
    avatar.changeParts("ahiru", 0);   // アヒル
    avatar.drawAvatar();  // アバター全体表示

    // ボイス再生
    playVoice(1, true);  // 「ちょっと休憩するのだ」★★★
    avatar.changeParts("mouth", 0);   // ボイス再生後は念のため口を戻す：口　閉じ　（むふ）
    avatar.drawAvatar();  // アバター全体表示
    interrupt = waitMillis(500);  // 待機（このループ内で待機する）★★★

    // 自動まばたきの再開
    if (!blink) {
      avatar.setBlink("eye", blinkOpen, 0);   // まばたき用のインデックス番号を設定する
      avatar.startAutoBlink();  // 自動まばたきスタート（タスク実行）
      blink = true;
      lastblink = blink;
    }

    // 休憩開始
    uint32_t tm2 = millis() + BREAK_TIME_LONG * 1000;
    uint32_t tmb = millis() + 500;
    uint16_t kp = 0;
    while (millis() < tm2) {
      // ぼよんぼよんする
      float scx[4] = { 1.0, 0.99, 0.98, 0.99 };
      float scy[4] = { 1.0, 1.01, 1.02, 1.01 };
      for (int i=0; i<4; i++) {
        interrupt = waitMillis(75);  // 待機（このループ内で待機する）★★★
        if (interrupt) break;
        avatar.scaleBodyCanvasY = scx[i];
        avatar.scaleBodyCanvasX = scy[i];
        // 手を上げ下げする
        if (tmb < millis()) {
          tmb = millis() + 500;
          if (kp % 2 == 0) {
            avatar.changeParts("rhand", 1);   // 右腕　腰
            avatar.changeParts("lhand", 1);   // 左腕　腰
            avatar.changeParts("mouth", 0);   // 口　閉じ　（むふ）
          } else {
            avatar.changeParts("rhand", 2);   // 右腕　上げ
            avatar.changeParts("lhand", 2);   // 左腕　上げ
            avatar.changeParts("mouth", 1);   // 口　普通　（ほあー）
          }
          kp++;
        }
        avatar.drawAvatar();
      } //for
      if (interrupt) break;
    } //while

    // 休憩終了
    avatar.scaleBodyCanvasY = 1.0;
    avatar.scaleBodyCanvasX = 1.0;
    defaultAvatarParts(); // アバターのパーツをデフォルトに戻す
    avatar.drawAvatar(); // アバター全体表示

    // ボイス再生
    playVoice(2, true);  // 「そろそろいいのだ」★★★
    avatar.changeParts("mouth", 0);   // ボイス再生後は念のため口を戻す：口　閉じ　（むふ）
    avatar.drawAvatar();  // アバター全体表示

    // ボタン押下判定のバッファクリア
    if (interrupt) {
      M5.update();
      M5.BtnA.wasReleased();
    }

    // 体力ゲージと距離ゲージを再表示する
    avatar.changeInsertedLayerPosition(0, OVR_FRONT_AVATER);   // 体力ゲージ
    if (SHOW_DISTANCE_GAUGE) avatar.changeInsertedLayerPosition(1, OVR_FRONT_AVATER);   // 距離ゲージ
    workingtime = 0;
    laststat = stat;
    stat = 1;
  } // if stat==4
}
